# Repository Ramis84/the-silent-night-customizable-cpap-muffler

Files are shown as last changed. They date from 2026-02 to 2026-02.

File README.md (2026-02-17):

# The "Silent Night" Customizable CPAP Muffler
This CPAP muffler/silencer can be used to dramatically reduce the noise travelling up the hose to the mask.

**NOTE:** This is compatible with standard rubber hose connectors (default 22mm, but it is customizable). If using the Resmed Airmini, or other travel CPAPs with non-standard hose connectors, an adapter will need to be used.

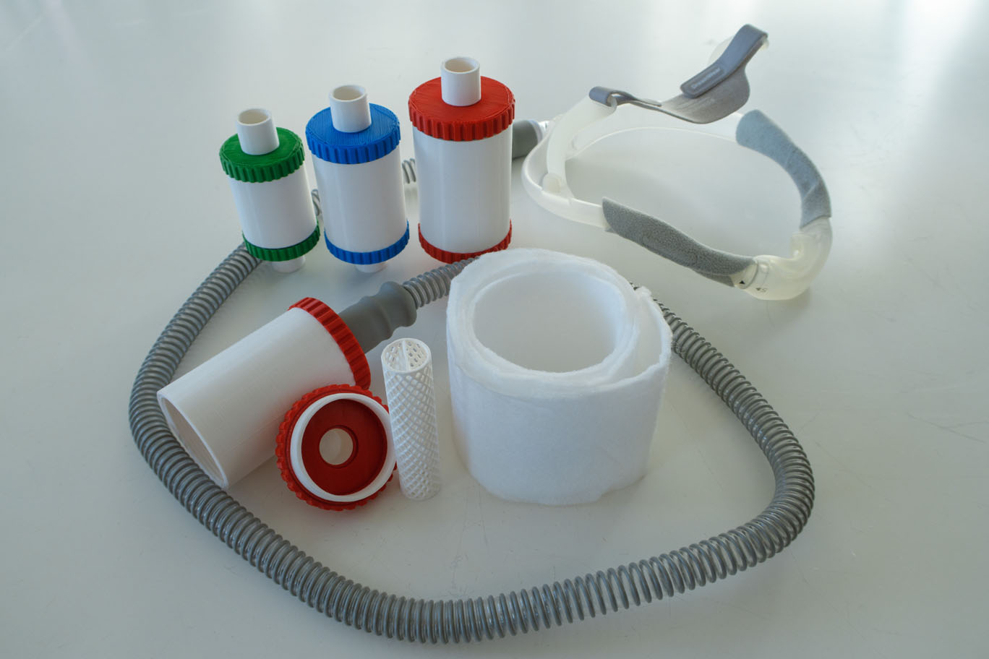
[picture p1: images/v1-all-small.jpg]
All sizes of the printed parts


## Introduction
While using my travel CPAP (a Breas Z1 Auto) for treating my sleep apnea, the noise travelling up the hose have been bothering me. I have tested a couple of mufflers on the market, like the Breas Q-Tube and Breas Q-Lite, but have not been satisfied with the sound reduction, so I have been requiring ear-plugs. This design is fully customizable, but I have included 3 sizes in different diameters, which will be enough for most people. Small (44 mm O-ring), Medium (47 mm O-ring) and Large (50 mm O-ring). The mufflers are also abailable in multiple lengths. I recommend the large variant with 100 mm body for most people, and later try out a smaller one if you are happy. Even the small design is quieter than the Breas Q-Tube/Q-Lite in my experience, so feel free to try them all out. Using these designs, I no longer have a need for ear plugs!

I designed this sound absorption muffler/silencer to be easy to print and assemble, and use common materials. The muffler consists of 3 printed parts: 
- **An outer cylinder body**, with male 22mm standard hose connector.
- **An end cap**, female *or* male standard 22mm connector, depending on if you want the muffler attached directly on the CPAP or on a hose.
- **An inner mesh tube**, which separates the sound absorption material from the air flow.

You will need some additional material to assemble the muffler, see the section **Required materials** below.

## Versions
There are two versions of this design:
- [v2-build123d](v2-build123d), which uses standard O-ring sizes and are easier to assemble and maintain. <br />
**Files available:** .STL & .STEP-files. And a .PY (Python/build123d) source file.
- [v1-openscad](v1-openscad), an older version with less options, and harder to find O-ring sizes. <br />
**Files available:** .STL-files. And a .SCAD (OpenSCAD) source file.

Always use the newer v2 model, unless you are printing spare parts for your old muffler.

## Required materials

### 1. Sound absorption material
You will need to add a sound absorption material sheet. Since this will come in contact with the air you breathe, avoid fabrics that lint and release small fibres, like cotton or fleece. Prefer materials like nonwoven polyester (PET) or polypropylene filter media, sheets like the ones that are used normally as air intake filters in CPAPs, those are made to not shed any material, so will be quite safe to use. You can look for universal filters for air conditioners or vents, those are sold in sheets you can cut. Please note that the purpose of this material is not to filter the air, it is just to absorb the vibrations travelling upp the tube. The air to the mask is supposed to travel through the inner tube without any obstructions.

### 2. O-rings
You will need an O-ring between the body and end-cap, to make it air-tight. If using the female end cap, you will need to add an extra O-ring.

These are the sizes used by each part, which are very common in O-ring kits:

| Version | O-ring size |
| --- | --- |
| Small body | 44 x 3.5 mm |
| Medium body | 47 x 3.5 mm |
| Large body | 50 x 3.5 mm |
| Female end-cap (optional) | 21 x 2.0 mm *or* 21 x 2.5 mm |

The large O-ring for the body can also be printed using a flexible material like TPU. Printing an O-ring for the female end-cap is difficult since it requires pretty tight tolerances, so it's not recommended.

### 3. Small hose for male end-cap (optional)
If you use the male end-cap, you will need a small hose in-between the CPAP and muffler, with standard rubber 22mm connectors.

## Assembly instructions:
After printing, make sure to test that the body and end-cap are completely air-tight before final assembly. Cover one end and blow hard into the other, and ensure that no air escapes any gap.

1. If using the female end cap, insert the 21 x 2.0 mm *or* 21 x 2.5 mm O-ring (depending on which version of the model you printed) into the slot on the inside of the connector.
2. Cut a sound absorption sheet into a long strip, slightly less wide than the inner tube.
3. Roll up the sound absorption sheet around the inner tube, so it forms a thick padding around the tube.
4. Insert the tube and absorption material together into the cylinder body. If it is too large, cut and reduce the length of the sheet.
5. Insert the large O-ring onto the end-cap.
6. Screw in the end-cap into the cylinder.
7. Test that the muffler is completely air-tight after assembly.

## Maintenance
In between uses, I recommend disassembling the muffler to prevent any mold. And just to be safe, discard and replace the fabric regularly, like you do with the air intake filter on the CPAP.

## File descriptions:

### Large sized muffler (recommended first print)

| Filename | Description |
| --- | --- |
| v2-body-male-large-100 | **100 mm** body using **50 x 3.5 mm** O-ring. (recommended) |
| v2-body-male-large-120 | **120 mm** body using **50 x 3.5 mm** O-ring. |
| v2-end-cap-male-large | End-cap, with **male** connector. |
| v2-end-cap-male-large-extra-spacing | End-cap, with **male** connector. Extra spacing between threads for larger tolerance. |
| v2-end-cap-female-large-2-0 | End-cap, with **female** connector. Uses a **21 x 2.0 mm** O-ring. |
| v2-end-cap-female-large-2-5 | End-cap, with **female** connector. Uses a **21 x 2.5 mm** O-ring. |
| v2-end-cap-female-large-2-0-extra-spacing | End-cap, with **female** connector. Uses a **21 x 2.0 mm** O-ring. Extra spacing between threads for larger tolerance. |
| v2-end-cap-female-large-2-5-extra-spacing | End-cap, with **female** connector. Uses a **21 x 2.5 mm** O-ring. Extra spacing between threads for larger tolerance. |
| v2-o-ring-large | Large sized printable o-ring (use flexible material, like TPU). |

### Medium sized muffler

| Filename | Description |
| --- | --- |
| v2-body-male-medium-85 | **85 mm** body using **47 x 3.5 mm** O-ring. |
| v2-body-male-medium-100 | **100 mm** body using **47 x 3.5 mm** O-ring. |
| v2-body-male-medium-120 | **120 mm** body using **47 x 3.5 mm** O-ring. |
| v2-end-cap-male-medium | End-cap, with **male** connector. |
| v2-end-cap-male-medium-extra-spacing | End-cap, with **male** connector. Extra spacing between threads for larger tolerance. |
| v2-end-cap-female-medium-2-0 | End-cap, with **female** connector. Uses a **21 x 2.0 mm** O-ring. |
| v2-end-cap-female-medium-2-5 | End-cap, with **female** connector. Uses a **21 x 2.5 mm** O-ring. |
| v2-end-cap-female-medium-2-0-extra-spacing | End-cap, with **female** connector. Uses a **21 x 2.0 mm** O-ring. Extra spacing between threads for larger tolerance. |
| v2-end-cap-female-medium-2-5-extra-spacing | End-cap, with **female** connector. Uses a **21 x 2.5 mm** O-ring. Extra spacing between threads for larger tolerance. |
| v2-o-ring-medium | Large sized printable o-ring (use flexible material, like TPU). |

### Small sized muffler

| Filename | Description |
| --- | --- |
| v2-body-male-small-70 | **70 mm** body using **44 x 3.5 mm** O-ring. |
| v2-body-male-small-85 | **85 mm** body using **44 x 3.5 mm** O-ring. |
| v2-body-male-small-100 | **100 mm** body using **44 x 3.5 mm** O-ring. |
| v2-body-male-small-120 | **120 mm** body using **44 x 3.5 mm** O-ring. |
| v2-end-cap-male-small | End-cap, with **male** connector. |
| v2-end-cap-male-small-extra-spacing | End-cap, with **male** connector. Extra spacing between threads for larger tolerance. |
| v2-end-cap-female-small-2-0 | End-cap, with **female** connector. Uses a **21 x 2.0 mm** O-ring. |
| v2-end-cap-female-small-2-5 | End-cap, with **female** connector. Uses a **21 x 2.5 mm** O-ring. |
| v2-end-cap-female-small-2-0-extra-spacing | End-cap, with **female** connector. Uses a **21 x 2.0 mm** O-ring. Extra spacing between threads for larger tolerance. |
| v2-end-cap-female-small-2-5-extra-spacing | End-cap, with **female** connector. Uses a **21 x 2.5 mm** O-ring. Extra spacing between threads for larger tolerance. |
| v2-o-ring-small | Large sized printable o-ring (use flexible material, like TPU). |

### Inner mesh tube (lengths are shared by all sizes of mufflers)

| Filename | Description |
| --- | --- |
| v2-inner-mesh-tube-70 | **70 mm** inner mesh tube, open. |
| v2-inner-mesh-tube-70-corkscrew | **70 mm** inner mesh tube, with a corkscrew wall inside. |
| v2-inner-mesh-tube-85 | **85 mm** inner mesh tube, open. |
| v2-inner-mesh-tube-85-corkscrew | **85 mm** inner mesh tube, with a corkscrew wall inside. |
| v2-inner-mesh-tube-100 | **100 mm** inner mesh tube, open. |
| v2-inner-mesh-tube-100-corkscrew | **100 mm** inner mesh tube, with a corkscrew wall inside. |
| v2-inner-mesh-tube-120 | **120 mm** inner mesh tube, open. |
| v2-inner-mesh-tube-120-corkscrew | **120 mm** inner mesh tube, with a corkscrew wall inside. |

## Dependencies / How to build
The project (v2, subfolder: [v2-build123d](v2-build123d)) is written using [build123d](https://github.com/gumyr/build123d), and [bd_warehouse](https://bd-warehouse.readthedocs.io/) is used to implement ISO Standard Threads. The parametric source file [The Silent Night Customizable CPAP Silencer-Muffler v2.py](v2-build123d/The%20Silent%20Night%20Customizable%20CPAP%20Silencer-Muffler%20v2.py) generates and exports all STL and STEP files when executed.

The original version (v1) was originally written in OpenSCAD. These obsoleted legacy files are still available in the subfolder [v1-openscad](v1-openscad) for archival reasons.

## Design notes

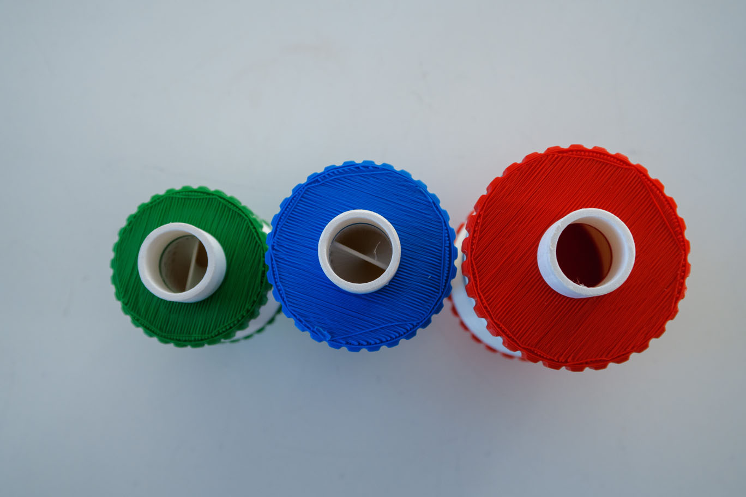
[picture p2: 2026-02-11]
images/v1-top-small.jpg

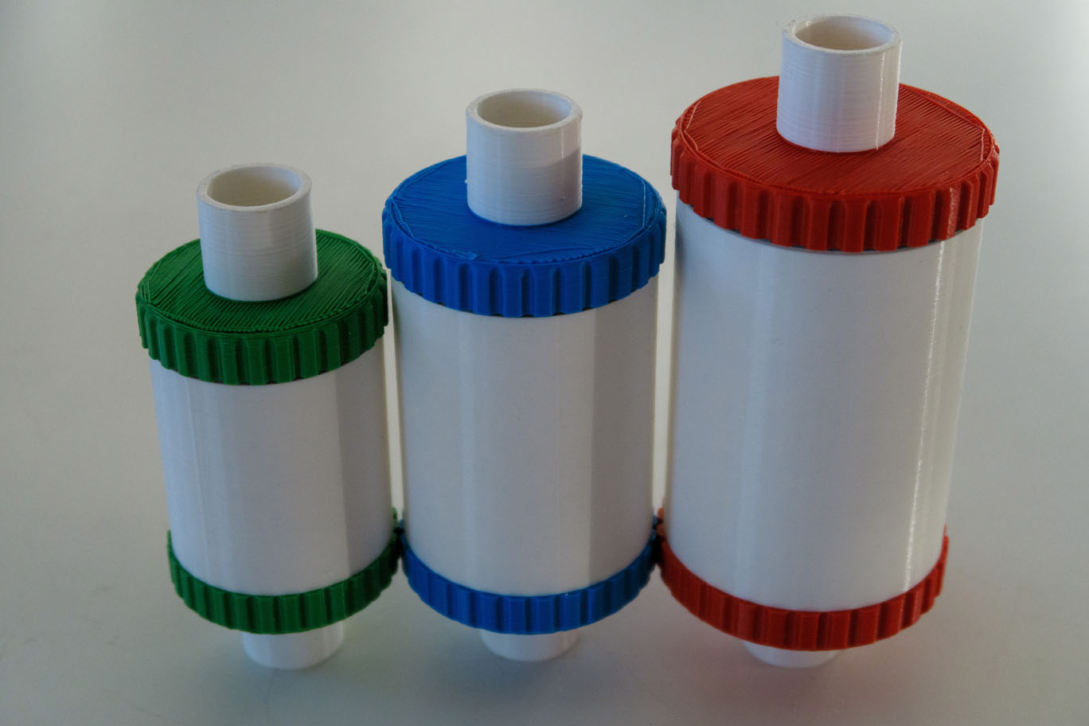
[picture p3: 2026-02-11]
images/v1-front-small.jpg

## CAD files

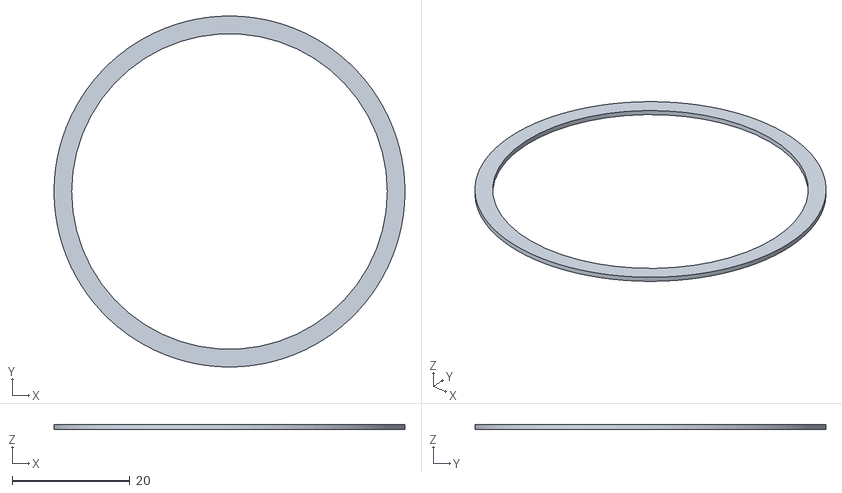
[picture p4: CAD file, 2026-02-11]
v1-openscad/v1-large-gasket.stl
59.5 x 59.5 x 0.8

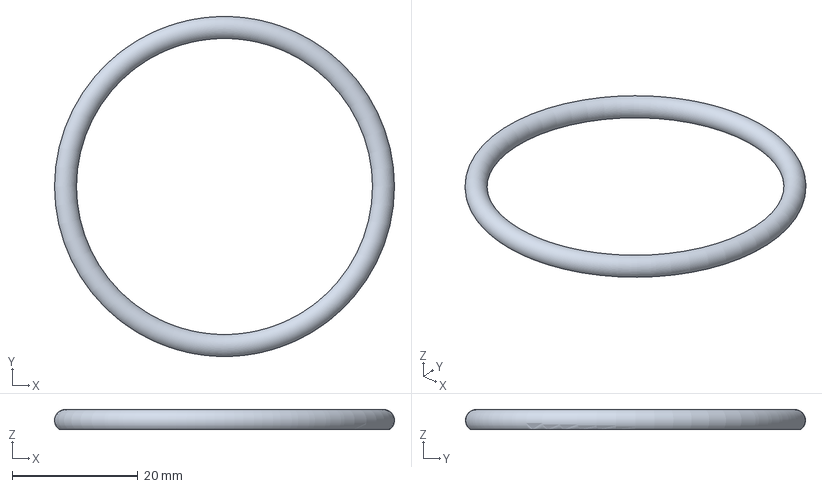
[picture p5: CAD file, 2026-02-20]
v2-build123d/v2-o-ring-medium.step
54.0 x 54.0 x 3.20 mm

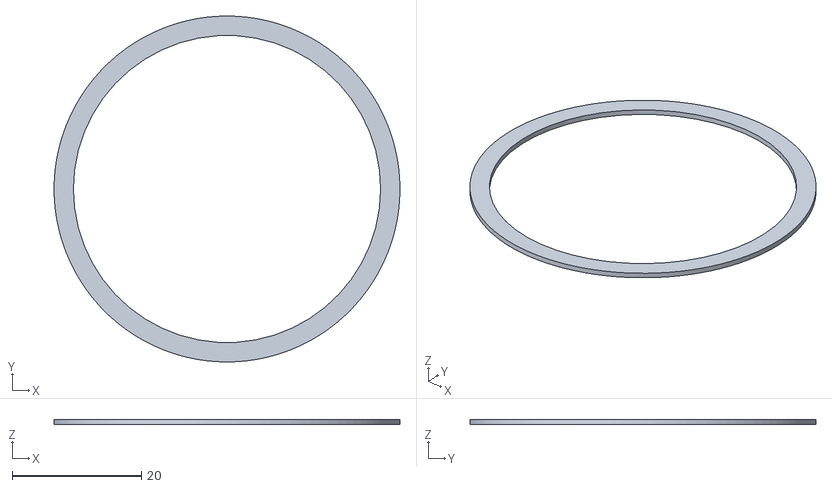
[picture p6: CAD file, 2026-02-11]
v1-openscad/v1-medium-gasket.stl
53.5 x 53.5 x 0.8

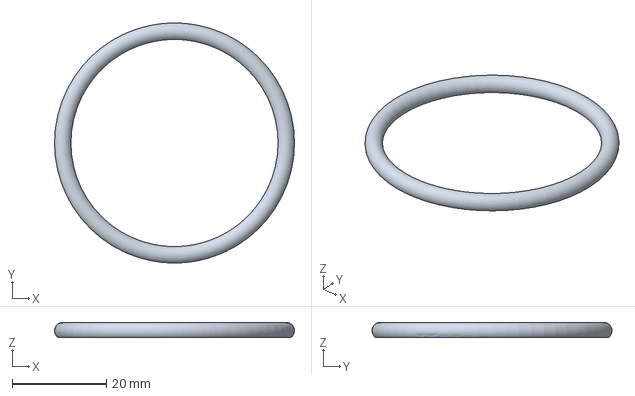
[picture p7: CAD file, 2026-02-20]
v2-build123d/v2-o-ring-small.step
51.0 x 51.0 x 3.20 mm

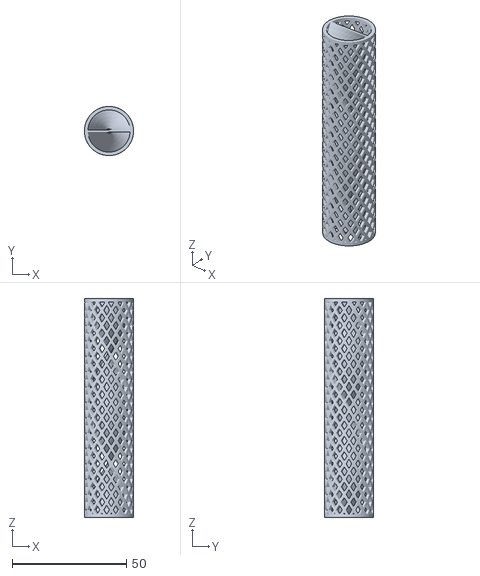
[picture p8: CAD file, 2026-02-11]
v1-openscad/v1-large-innertube.stl
21.6 x 21.6 x 96.0

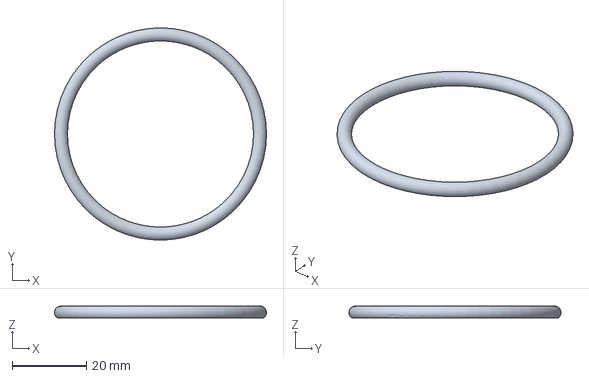
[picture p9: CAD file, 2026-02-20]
v2-build123d/v2-o-ring-large.step
57.0 x 57.0 x 3.20 mm

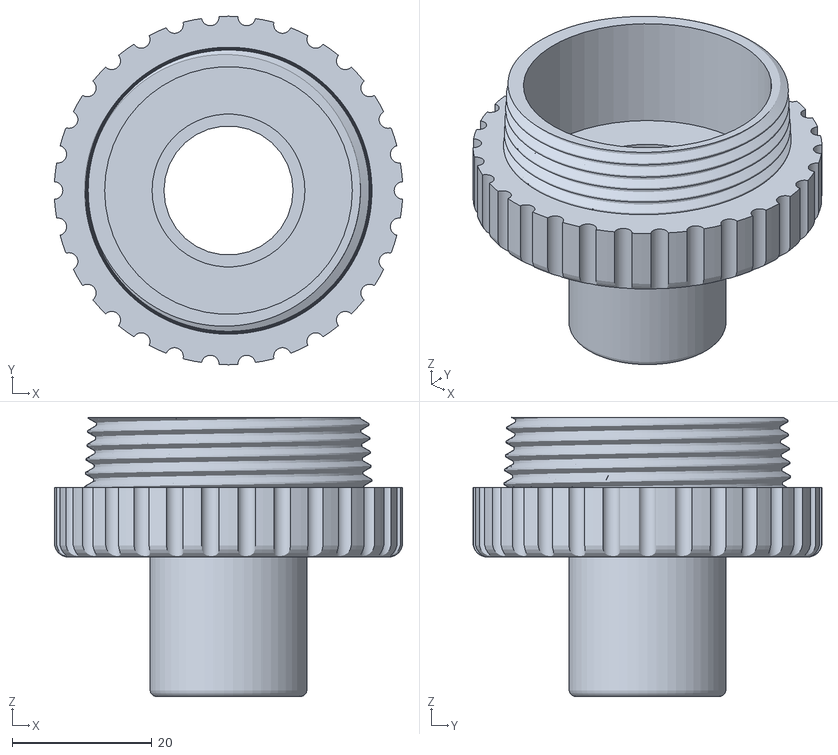
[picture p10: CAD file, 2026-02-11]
v1-openscad/v1-small-endcap-male.stl
49.9 x 50.0 x 40.0

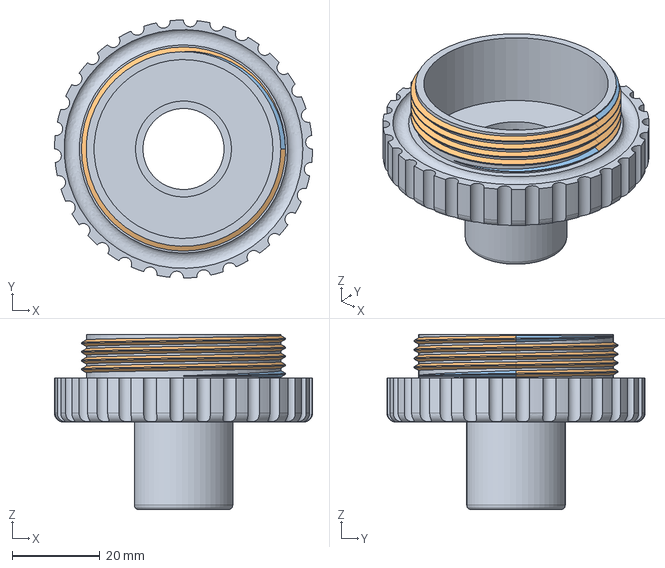
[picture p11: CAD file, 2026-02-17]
v2-build123d/v2-end-cap-male-medium-extra-spacing.step
58.9 x 58.9 x 40.0 mm

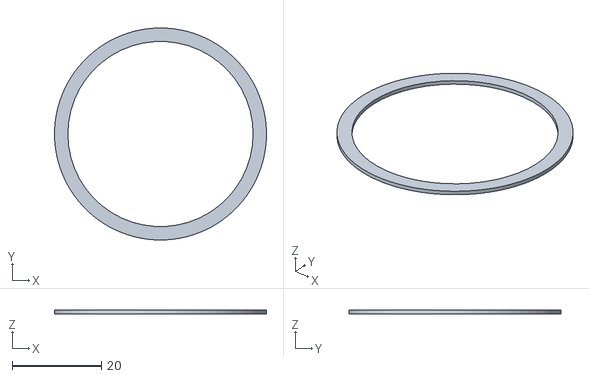
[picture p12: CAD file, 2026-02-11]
v1-openscad/v1-small-gasket.stl
47.5 x 47.5 x 0.8

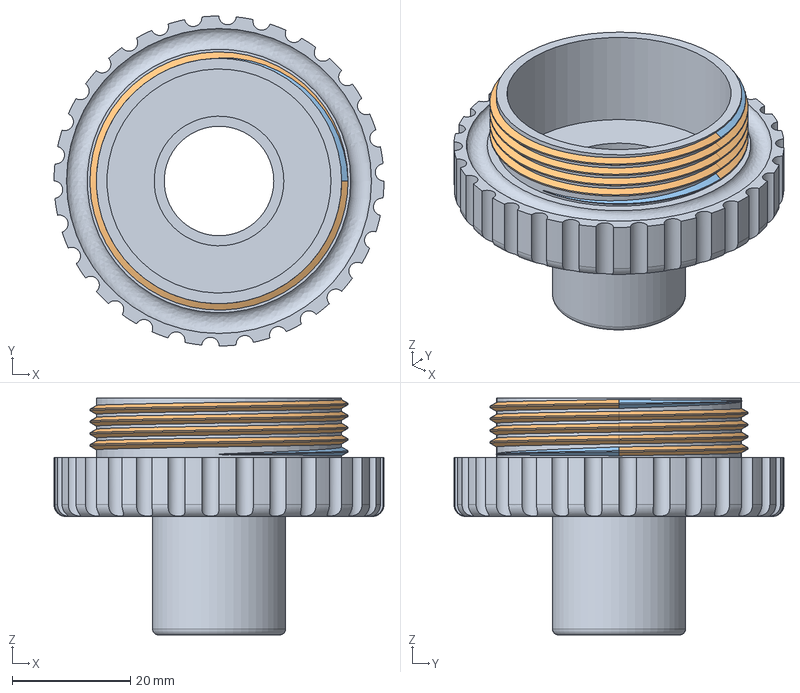
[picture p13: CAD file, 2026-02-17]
v2-build123d/v2-end-cap-male-small-extra-spacing.step
55.7 x 55.7 x 40.0 mm

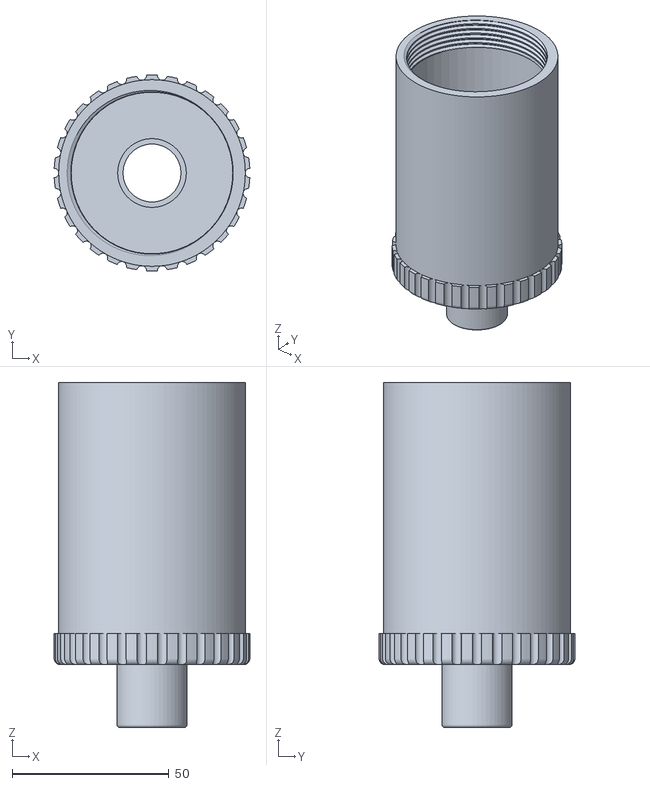
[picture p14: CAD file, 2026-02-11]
v1-openscad/v1-large-body.stl
62.4 x 62.5 x 110.0

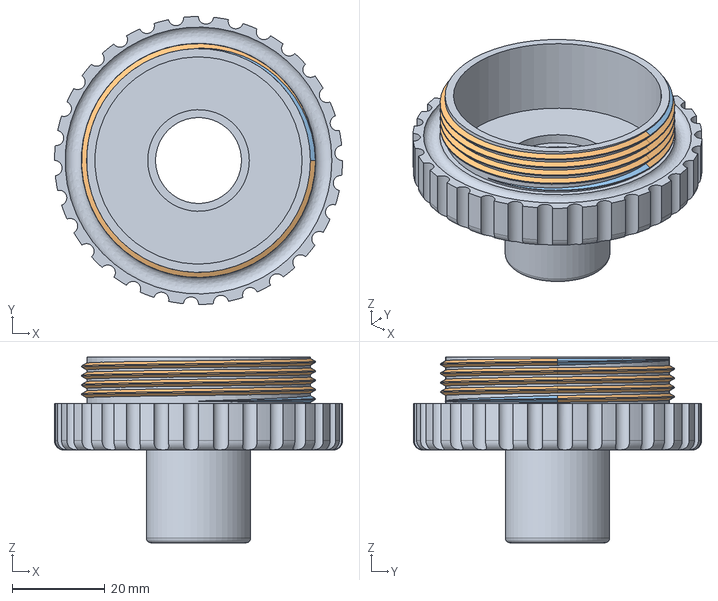
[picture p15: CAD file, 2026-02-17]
v2-build123d/v2-end-cap-male-large.step
62.1 x 62.1 x 40.0 mm

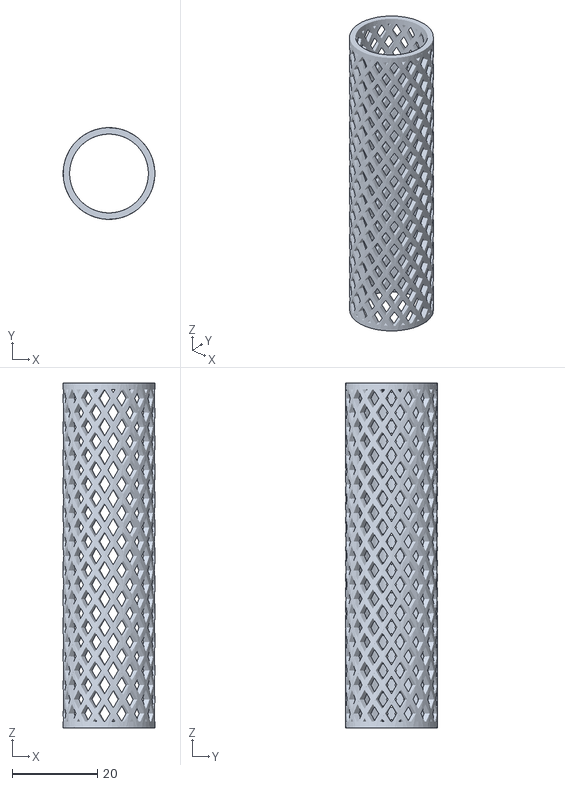
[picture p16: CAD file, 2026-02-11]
v1-openscad/v1-medium-innertube-open.stl
21.6 x 21.6 x 81.0

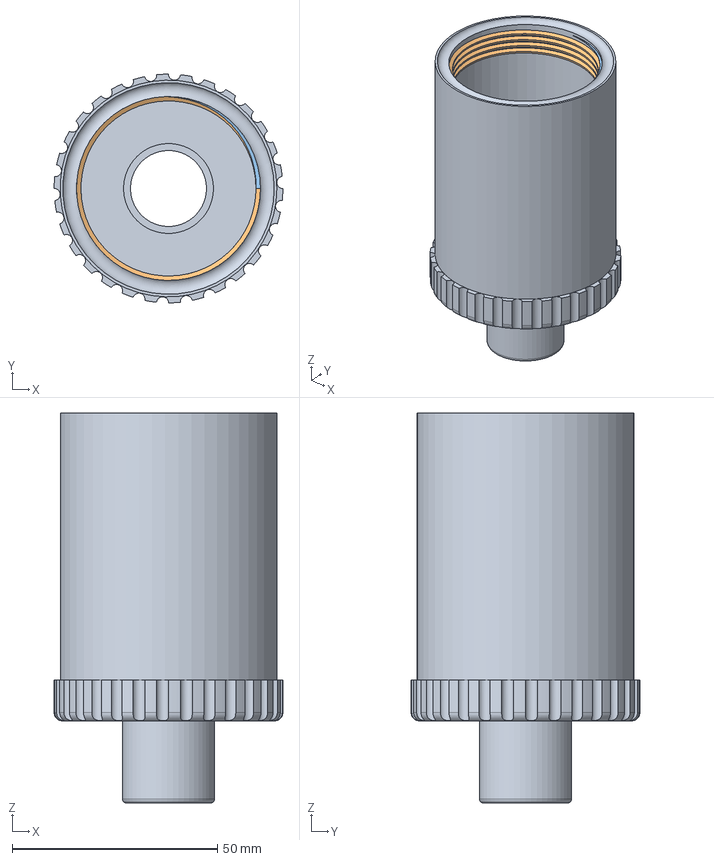
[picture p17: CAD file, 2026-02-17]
v2-build123d/v2-body-male-small-85.step
55.7 x 55.7 x 95.0 mm

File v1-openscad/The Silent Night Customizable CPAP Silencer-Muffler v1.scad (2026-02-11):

// Type of part to render
Part = "AllFemale"; // [AllFemale, AllMale, Combined, MufflerBase, InnerTube, EndCapMale, EndCapFemale, Gasket]

// Length of the outer tube+endcaps, excluding connectors
Muffler_Length = 100; // [20:1:200]

// The length of connector
Connector_Length = 20; // [0:1:30]

// Diameter of tube connector
Connector_Male_Outer_Diameter = 22.5; // [0:0.1:30]

// Extra spacing added for parts that are assembled together, increase if too tight
Tolerance = 0.2; // [0:0.05:0.5]

/* [Seal-edge] */

// Enable the extra edge, which may make it easier to make it air-tight
Enable_Seal_Edge = false;

/* [Connector] */

// Thickness of the male connector wall
Connector_Male_Wall_Thickness = 2; // [0.1:0.1:4]

// Thickness of the female connector wall
Connector_Female_Wall_Thickness = 3; // [0.1:0.1:4]

// The rounding radius of the connector edge
Connector_Corner_Radius = 1; // [0:0.1:4]

// The rounding radius of the connector edge
Female_Connector_O_Ring_Thickness = 2; // [0:0.1:4]

/* [Body] */

// The thickness of the outside tube
Muffler_Wall_Thickness = 4; // [0.1:0.1:10]

// The length of the chamber (radius difference) between inner tube and outside wall
Chamber_Thickness = 15; // [0:1:30]

/* [End cap] */

// The rounding radius of the end cap/outer tube
End_Cap_Corner_Radius = 2; // [0:0.1:4]

// The thickness of the end cap wall
End_Cap_Thickness = 4; // [0:0.1:10]

// The thickness of the end cap wall
End_Cap_Grip_Thickness = 10; // [0:1:50]

// The recess depth inside the endcap, where the inner tube is resting
End_Cap_Recess_For_Inner_Tube = 2; // [0:0.1:5]

// The length of the end cap insert
End_Cap_Insert_Length = 10; // [0:1:50]

// The thickness of the end cap insert
End_Cap_Insert_Thickness = 2; // [0:0.1:3]

// The number of cutouts making a grip in the end cap
End_Cap_Grip_Cutout_Count = 30; // [0:1:50]

// The diameter of each cutout in the grip
End_Cap_Grip_Cutout_Diameter = 3; // [0.1:0.1:5]

/* [Threading] */

// The pitch of the threading
Threading_Pitch = 2.0; // [0:0.1:4]

// The number of starts in the threading
Threading_N_Starts = 1; // [1:1:10]

// Makes the end of the threading smaller, so its easier to insert
Threading_Taper = 0.1; // [0:0.01:1]

// Extra spacing between outer shell and end cap thread, to increase tolerance.
Threading_Extra_Spacing = 0.0;

/* [Inner tube/mesh] */

// Enable/Disable inside screw
Inner_Tube_Screw_Enabled = true;

// The thickness of the inner tube screw
Inner_Tube_Screw_Thickness = 1; // [0:0.1:3]

// Extra length added to inner tube. Useful if using rubber gaskets between outer tube and end caps.
Inner_Tube_Extra_Length = 0; // [0:0.1:3]

// The number of turns (360 degrees) of the inside screw.
Inner_Tube_Screw_Twist_Turns = 1; // [0:0.1:3]

// The thickness of the inner tube wall/mesh
Inner_Tube_Mesh_Thickness = 1.5; // [0:0.1:3]

// The number of mesh lines
Inner_Tube_Mesh_Count = 15; // [50]

// The angle (degrees) in the mesh pattern.
Inner_Tube_Mesh_Twist_Angle = 35; // [0:1:70]

/* [Gasket (Optional)] */

// The thickness of the optional gasket
Gasket_Thickness = 0.8;

// Calculations
Connector_Male_Inner_Diameter = Connector_Male_Outer_Diameter - 2*Connector_Male_Wall_Thickness;
Connector_Female_Outer_Diameter = Connector_Male_Outer_Diameter + 2*Connector_Female_Wall_Thickness;
Inner_Tube_Diameter = Connector_Male_Inner_Diameter+2*Inner_Tube_Mesh_Thickness;
Inner_Tube_Length = Muffler_Length-2*End_Cap_Thickness+2*End_Cap_Recess_For_Inner_Tube+Inner_Tube_Extra_Length;
Outer_Tube_Length = Muffler_Length-2*End_Cap_Grip_Thickness;
Outer_Tube_Inner_Diameter = Inner_Tube_Diameter+2*Chamber_Thickness;
Outer_Tube_Outer_Diameter = Outer_Tube_Inner_Diameter+2*Muffler_Wall_Thickness;

module inner_tube_inner_screw() {
    linear_extrude(Inner_Tube_Length, twist=Inner_Tube_Screw_Twist_Turns*360, slices=50) {
        translate([-Connector_Male_Inner_Diameter/2, -0.5, 0])
            square([Connector_Male_Inner_Diameter,Inner_Tube_Screw_Thickness]);
    }
}

module inner_tube_end_ring() {
    rotate_extrude(angle = 360, $fn = 50) {
        translate([Connector_Male_Inner_Diameter/2,0,0]) {
            square(Inner_Tube_Mesh_Thickness);
        }
    }
}

module inner_tube_mesh() {
    for (angle = [0 : 360/Inner_Tube_Mesh_Count : 359]) {
        linear_extrude(Inner_Tube_Length, twist=tan(Inner_Tube_Mesh_Twist_Angle)*360*Inner_Tube_Length/(Connector_Male_Outer_Diameter*PI)) {
            rotate(angle) {
                translate([Connector_Male_Inner_Diameter/2,-Inner_Tube_Mesh_Thickness/2,0]) {
                    square(Inner_Tube_Mesh_Thickness);
                }
            }
        }
        if (Inner_Tube_Mesh_Twist_Angle > 0) {
            linear_extrude(Inner_Tube_Length, twist=-tan(Inner_Tube_Mesh_Twist_Angle)*360*Inner_Tube_Length/(Connector_Male_Outer_Diameter*PI)) {
                rotate(angle) {
                    translate([Connector_Male_Inner_Diameter/2,-Inner_Tube_Mesh_Thickness/2,0]) {
                        square(Inner_Tube_Mesh_Thickness);
                    }
                }
            }
        }
    }
}

module inner_tube() {
    if (Inner_Tube_Screw_Enabled) {
        inner_tube_inner_screw();
    }
    if (Inner_Tube_Mesh_Count > 0) {
        inner_tube_mesh();
        inner_tube_end_ring();
        translate([0,0,Inner_Tube_Length-Inner_Tube_Mesh_Thickness]) {
            inner_tube_end_ring();
        }
    }
}

module threading(diameter, length, internal=false, taper=0) {
    metric_thread (diameter=diameter, pitch=Threading_Pitch, length=length, n_starts=Threading_N_Starts,internal=internal,taper=taper);
}

module seal_edge(removeLength = 0) {
    rotate_extrude(angle = 360, $fn = 100) {
        translate([Outer_Tube_Outer_Diameter/2-1.5,0])
            difference() {
                polygon([[1,0],[-1,0],[0,1]]);
                translate([0,1])
                    square(removeLength*2, center=true);
            }
    }
}

module grip(includeThreading = false) {
    difference() {
        union() {
            difference() {
                translate([0,0,End_Cap_Corner_Radius])
                {
                    minkowski() {
                        cylinder(d=Outer_Tube_Outer_Diameter-2*End_Cap_Corner_Radius+End_Cap_Grip_Cutout_Diameter, h = End_Cap_Grip_Thickness, $fn = 100);
                        sphere(r=End_Cap_Corner_Radius, $fn = 20);
                    }
                }
                translate([0,0,End_Cap_Grip_Thickness])
                    cylinder(d=2*Outer_Tube_Outer_Diameter, h = 10*End_Cap_Grip_Thickness);
            }
            if (includeThreading) {
                translate([0,0,End_Cap_Grip_Thickness])
                    //cylinder(End_Cap_Insert_Length, d=Outer_Tube_Inner_Diameter+2, $fn = 50);
                    threading(diameter = Outer_Tube_Inner_Diameter+2-2*Threading_Extra_Spacing-2*Tolerance, length=End_Cap_Insert_Length, taper=Threading_Taper);
            }
        }
        union() {
            translate([0,0,End_Cap_Thickness-End_Cap_Recess_For_Inner_Tube-Tolerance])
                cylinder(d=Inner_Tube_Diameter+2*Tolerance, h = End_Cap_Insert_Length+1, $fn = 50);
            translate([0,0,End_Cap_Thickness])
                cylinder(d=Outer_Tube_Inner_Diameter-2*End_Cap_Insert_Thickness, h = End_Cap_Grip_Thickness+End_Cap_Insert_Length+1, $fn = 50);
            for (angle = [0 : 360/End_Cap_Grip_Cutout_Count : 359]) {
                translate([cos(angle)*(Outer_Tube_Outer_Diameter+End_Cap_Grip_Cutout_Diameter)/2,sin(angle)*(Outer_Tube_Outer_Diameter+End_Cap_Grip_Cutout_Diameter)/2,-0.5])
                    cylinder(h = 2*End_Cap_Grip_Thickness, d = End_Cap_Grip_Cutout_Diameter, $fn = 50);
            }
            
            if (Enable_Seal_Edge)
                translate([0,0,End_Cap_Grip_Thickness+0.4]) // Reduce space in seal, so it becomes tight
                    rotate([180,0,0])
                        seal_edge();
        }
    }
}
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

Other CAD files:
v1-openscad/v1-large-endcap-male.stl
v2-build123d/v2-end-cap-female-medium-2-5-extra-spacing.step
v1-openscad/v1-medium-body-with-edge.stl
v1-openscad/v1-small-body.stl
v1-openscad/v1-large-body-with-edge.stl
v1-openscad/v1-large-endcap-female-with-edge.stl
v1-openscad/v1-large-endcap-female.stl
v1-openscad/v1-large-endcap-male-with-edge.stl
v1-openscad/v1-medium-body.stl
v1-openscad/v1-medium-endcap-female-with-edge.stl
v1-openscad/v1-medium-endcap-female.stl
v1-openscad/v1-medium-endcap-male-with-edge.stl
v1-openscad/v1-medium-endcap-male.stl
v1-openscad/v1-medium-innertube-screw.stl
v1-openscad/v1-small-body-with-edge.stl
v1-openscad/v1-small-endcap-female-with-edge.stl
v1-openscad/v1-small-endcap-female.stl
v1-openscad/v1-small-endcap-male-with-edge.stl
v1-openscad/v1-small-innertube.stl
v2-build123d/v2-body-male-large-100.step
v2-build123d/v2-body-male-large-100.stl
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

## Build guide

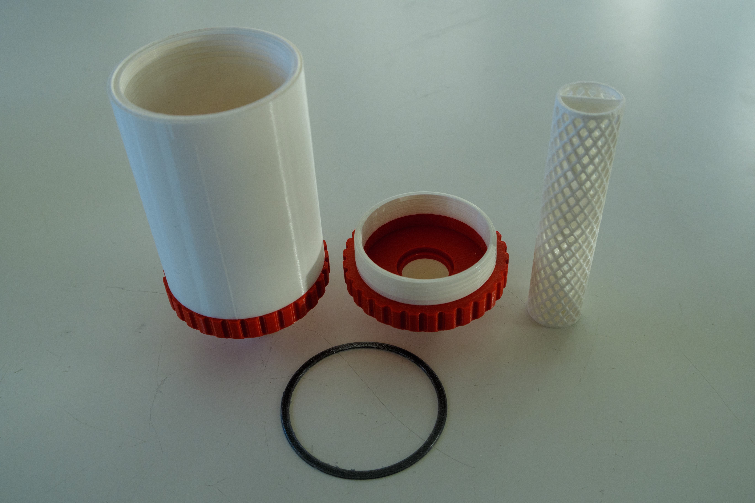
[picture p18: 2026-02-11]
images/v1-disassembled-large.jpg

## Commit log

2026-02-11 v1 version of muffler
    [The Silent Night Customizable CPAP Silencer-Muffler v1.scad, v1-large-body-with-edge.stl, v1-large-body.stl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]
2026-02-17 v2-build123d (#1)
    * draft 1
    * Inner mesh tube
    Parameter for threading extra spacing
    Cleanup
    * Fixed mesh
    * Cleanup
    * Auto grip cutout sizing
    Fixed female o-ring
    Some exports
    * Exports
    * Commented out preview code
    * Cleanup
    * Cleanup thread extra spacing
    * Parameter typing, cleanup
    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
    [v2-body-male-large-100.step, v2-body-male-large-100.stl, v2-body-male-large-120.step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]
2026-02-20 Fixed O-rings
    [v2-o-ring-large.step, v2-o-ring-large.stl, v2-o-ring-medium.step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]
